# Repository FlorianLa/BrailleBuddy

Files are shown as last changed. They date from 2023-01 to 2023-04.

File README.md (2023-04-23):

#### General Information and Disclaimer
This repository is linked with a scientific publication, which you can find here (https://dl.acm.org/doi/10.1145/3544548.3580844). The HTML version of the article can be accessed here (https://dl.acm.org/doi/fullHtml/10.1145/3544548.3580844). The PDF is contained in this repository.

Our work is published under GNU GPLv3. However, for some files, e.g., 3D figurines or the published paper, other licenses may apply. 
This repository (or rather the releases of this repository) is mirrored on Zenodo.org (https://doi.org/10.5281/zenodo.7606193).

If you use or extend our work, please cite us as (see bibtex_LangEtAl_BrailleBuddy.bib):

*Florian Lang, Verena Pues, Albrecht Schmidt, and Tonja-Katrin Machulla. 2023. BrailleBuddy: A Tangible User Interface to Support Children with Visual Impairment in Learning Braille. In Proceedings of the 2023 CHI Conference on Human Factors in Computing Systems (CHI '23). Association for Computing Machinery, New York, NY, USA, Article 218, 1–14. https://doi.org/10.1145/3544548.3580844*

## BrailleBuddy

BrailleBuddy is a tangible user interface supporting children with visual impairments in learning Braille. It was created using a human-centered inclusive design process with interviews, six design iterations with prototypes, and feedback from experts, students, and teachers. Alleviating the need for supervision, the device can be used during breaks in school or at home, providing additional opportunities to experience Braille and individual audio feedback to support the users in learning to read and spell Braille.

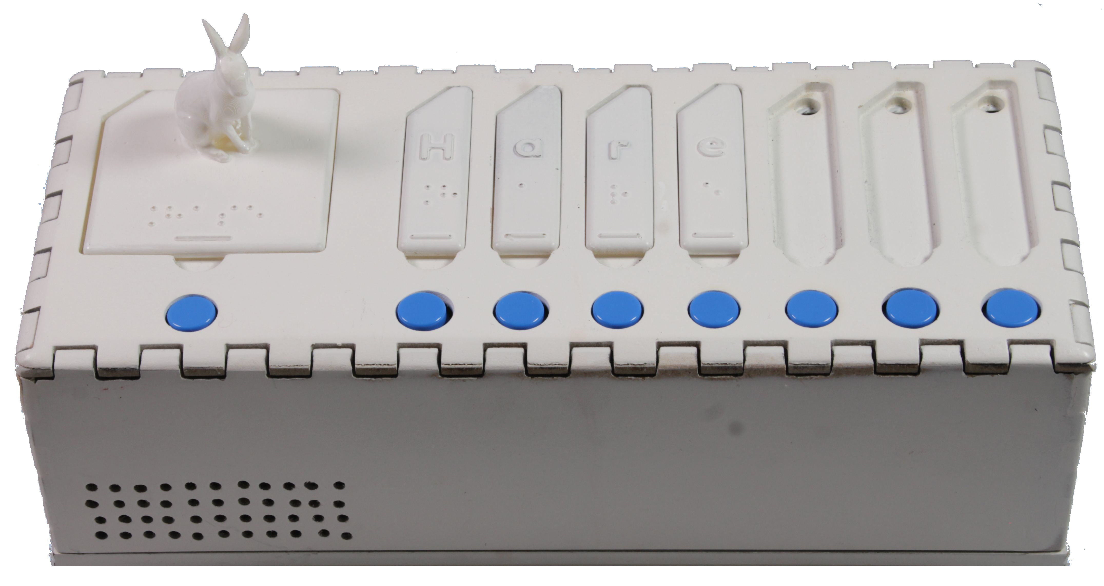
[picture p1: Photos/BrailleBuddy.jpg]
BrailleBuddy


### Case and 3D-printed Cards
We provide a *.svg file for the wooden case of BrailleBuddy in "CaseModel(Lasercutter)". The lid is constructed from two layers of wood. Please be aware, that the files are designed for material with 3mm thickness for each of the layers of the lid and 5mm for the other parts. If you use other materials, you need to adjust the contact areas accordingly.

Further, we provide language specific 3D-models for all cards used. **Right now only the German version is populated, but the models can be used by changing the Braille text beneath the figurine.**
The sources for the 3D figurines are listed next to each card. The 2D relief images were created by [Verena Pues](https://verenapues.com/).

### Supported Languages

**German** - with Braille system "Vollbraille". This version was used in the study.

**English** - with Braille system English Grade 2 Braille **(under construction)** 
For the English version, some points need to be completed, such as audio files and letter cards for abbreviations and English game and word cards.

To adjust the source code for the English version please comment out sections marked with GERMAN VERSION and comment in sections with ENGLISH VERSION

### Hardware

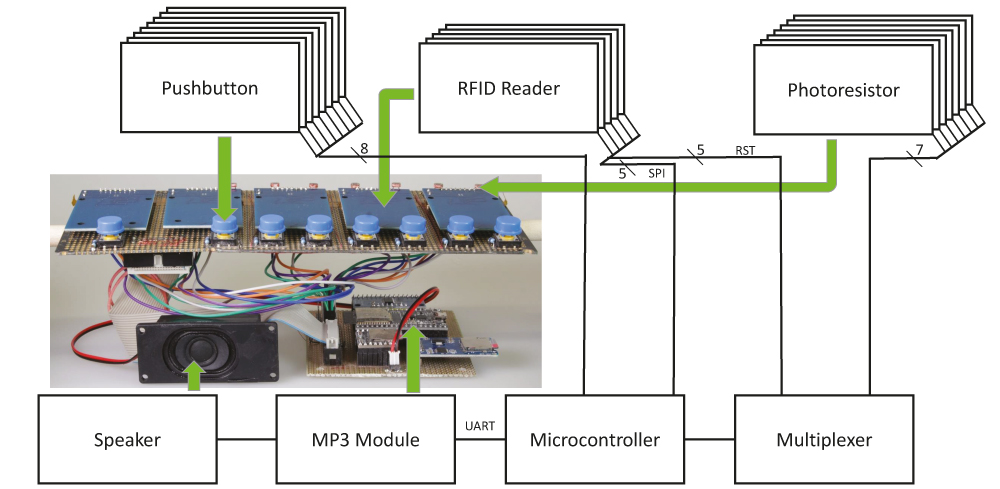
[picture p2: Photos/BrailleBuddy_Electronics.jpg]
Hardware


* **Microcontroller:** The brain of BrailleBuddy is an ESP32 microcontroller board that is easy to program, supports a variety of protocols, and has 27 usable General Purpose Input/Output (GPIO) pins. The board also has Wifi and Bluetooth functionality, which offers numerous possibilities for further development of BraillyBuddy. For other microcontrollers please check if there are enough GPIO pins and adjust the pin layout.
* **NFC Tags:** To store digital information on our game cards, we used NFC Stickers (12 x 19 mm - NTAG213 - 180 Byte - transparent).
* **RFID Readers:** To detect game cards and read and write the digital information, we used 5 x Mifare RFID-RC522 Modules, which communicate with the microcontroller via the SPI interface.
* **Photoresistors:** While the readers are responsible for receiving the information from the NFC tags, we used 7 x light dependent photoresistors to determine the corresponding position for each tag on the box as most of the readers cover two slots. 
* **Multiplexer:** We used a 16 channel digital/analog multiplexer to handle the various needed connections, i.e., to read out the analog signals from the photoresistors and distribute the RFID reader's reset line (RST).
* **MP3 Module and Loudspeaker:** For the auditory feedback, we used a DFPlayer-Mini – a compact serial MP3 module with a built-in amplifier and an SD card slot to store MP3 files – and a small 3 Watt 8 Ohm
loudspeaker.
* **Buttons:** To allow users to repeat the slot-related audio feedback, we used 8 x push buttons (12 x 12 x 7.3 mm).
* **Resistors:** To find out which and how many resistors you need, please consult the respective data sheets of your modules.

### Improvements
We describe various possible improvements for BrailleBuddy in our paper. The most relevant possibilities are:
* Add a headphone connector and an interface to control the volume.
* Instead of reading the word, BrailleBuddy could also make corresponding sounds, e.g., a car or animal sounds.
* Consider differently shaped cards to support users that find correctly rotating and placing the cards challenging.
* Use separate storage areas for the letter cards or reduce the selection of cards presented to support children just starting to learn Braille.
* The audio feedback can be improved by reacting to a button being pressed consecutively multiple times, long times in between cards placed, and multiple incorrectly placed cards. BrailleBuddy could give more diverse responses, e.g., "You placed the correct letter but in the wrong spot." or give hints towards the games solution.

### Pin Layout

| **ESP32 Pin** | **Note** | **Multiplexer** | **MP3 Module** | **RFID Reader** | **Button** |
|---|---|---|---|---|---|
| GPIO 0 | | S1 | | | |
| GPIO 1 | TX | | TX | | |
| GPIO 2 | | S0 | | | |
| GPIO 3 | RX | | RX | | |
| GPIO 4 | | S2 | | | |
| GPIO 5 | | | | No. 3, SDA | |
| GPIO 6 | SPI bus for flash memory, do not use! | | | | |
| GPIO 7 | SPI bus for flash memory, do not use! | | | | |
| GPIO 8 | SPI bus for flash memory, do not use! | | | | |
| GPIO 9 | SPI bus for flash memory, do not use! | | | | |
| GPIO 10 | SPI bus for flash memory, do not use! | | | | |
| GPIO 11 | SPI bus for flash memory, do not use! | | | | |
| GPIO 12 | | | | | |
| GPIO 13 | | | | No. 4, SDA | |
| GPIO 14 | | | | | No. 8 |
| GPIO 15 | used as Reader RST Pin | SIG | | | |
| GPIO 16 | | S3 | | | |
| GPIO 17 | | | | No. 5, SDA | |
| GPIO 18 | CLK | | | All, SCK | |
| GPIO 19 | MISO | | | All, MISO | |
| GPIO 21 | | | | No. 2, SDA | |
| GPIO 22 | | | | No. 1, SDA | |
| GPIO 23 | MOSI | | | All, MOSI | |
| GPIO 25 | | | | | No. 5 |
| GPIO 26 | | | | | No. 6 |
| GPIO 27 | | | | | No. 7 |
| GPIO 32 | | | | | No. 3 |
| GPIO 33 | | | | | No. 4 |
| GPIO 34 | only input | | | | No. 1 |
| GPIO 35 | only input | | | | No. 2 |
| GPIO 36 | only input | | | | |
| GPIO 39 | only input | | BUSY | | |

### Audio Files

We used the following free text-to-speech converter to create most audio files: https://ttsmp3.com/.

The sources of the sound effects used are:
* wrong answer: https://pixabay.com/de/sound-effects/wrong-answer-126515/
* correct answer: https://pixabay.com/de/sound-effects/success-1-6297/
* evaluation drums: https://pixabay.com/de/sound-effects/tadaa-47995/
* dice rolling for word scramble game intro: https://pixabay.com/de/sound-effects/dice-cup-60668/

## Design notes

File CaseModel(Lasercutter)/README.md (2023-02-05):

## BrailleBuddy Case

Dimensions: 250 x 105 x 80 mm

Braille Buddy's Box case was made from MDF wood boards (3mm and 5mm) using a Lasercutter.
All Elements were cut from 5mm thick boards, except the box lid. 
The lid consists of two layers, each 3mm thick. The bottom layer serves as a storage surface for the playing cards while the top layer contains the indentations that show where cards can be placed.

For a more pleasant touch experience, the wooden surface has been sanded, the corners rounded and the entire box lacquered.

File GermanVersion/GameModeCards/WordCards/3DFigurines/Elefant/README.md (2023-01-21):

Based on:
"G象（Elephant）3Dデータ" by YahooJAPAN
https://www.thingiverse.com/thing:182136
licensed under the Creative Commons - Attribution license (https://creativecommons.org/licenses/by/4.0/)

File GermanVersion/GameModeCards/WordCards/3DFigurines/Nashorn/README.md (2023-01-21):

Based on:
"サイ（Rhino）3Dデータ" by YahooJAPAN
https://www.thingiverse.com/thing:182261
licensed under the Creative Commons - Attribution license (https://creativecommons.org/licenses/by/4.0/)

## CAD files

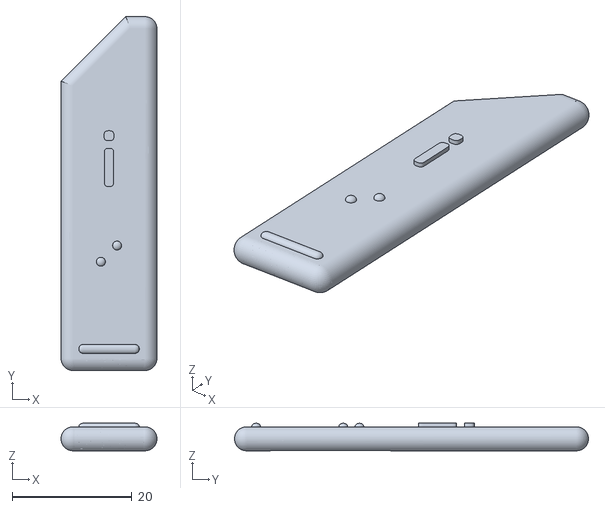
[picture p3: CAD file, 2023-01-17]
EnglishVersion/LetterCards/Lowercase/i.stl
16.0 x 59.0 x 4.60

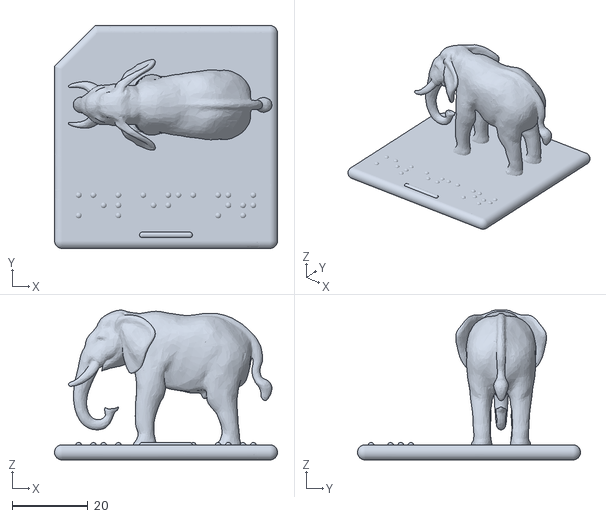
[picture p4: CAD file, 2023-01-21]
GermanVersion/GameModeCards/WordCards/3DFigurines/Elefant/Elefant_3D.stl
59.0 x 59.0 x 39.7

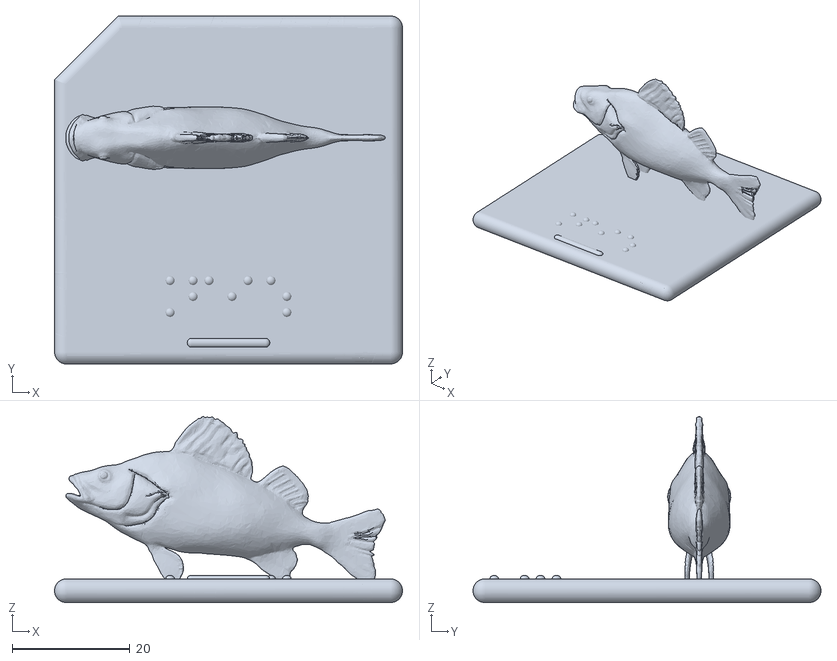
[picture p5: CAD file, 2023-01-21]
GermanVersion/GameModeCards/WordCards/3DFigurines/Fisch/Fisch_3D.stl
59.0 x 59.0 x 31.5

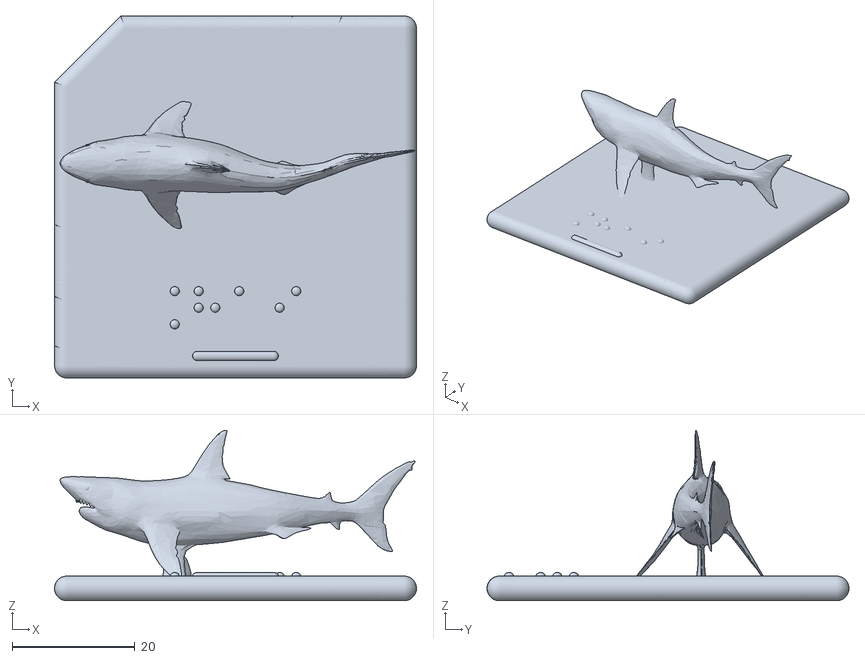
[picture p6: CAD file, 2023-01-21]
GermanVersion/GameModeCards/WordCards/3DFigurines/Hai/Hai_3D.stl
59.0 x 59.0 x 27.8

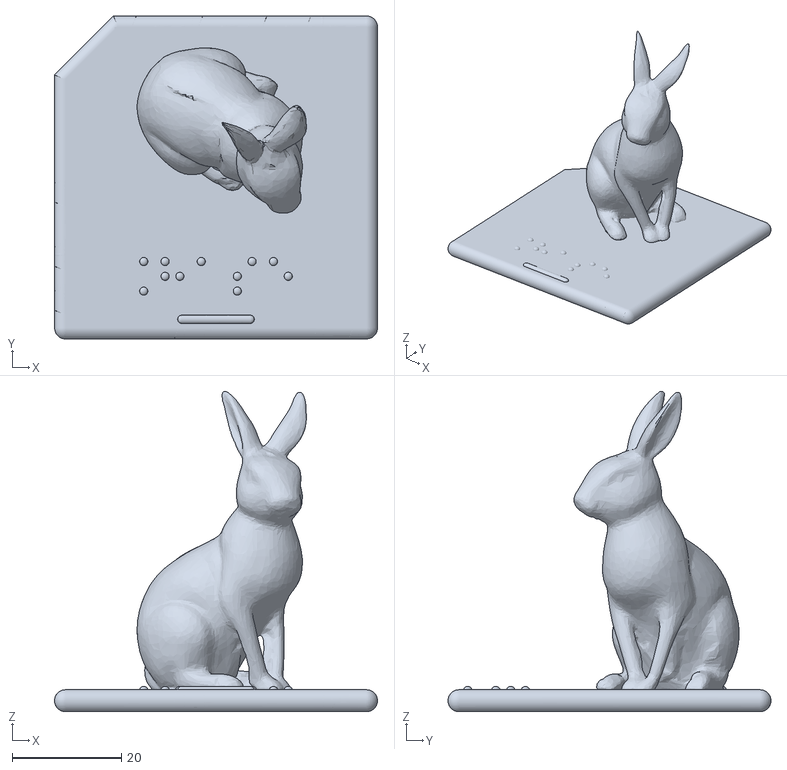
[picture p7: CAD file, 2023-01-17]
GermanVersion/GameModeCards/WordCards/3DFigurines/Hase/Hase_3D.stl
59.0 x 59.0 x 58.5

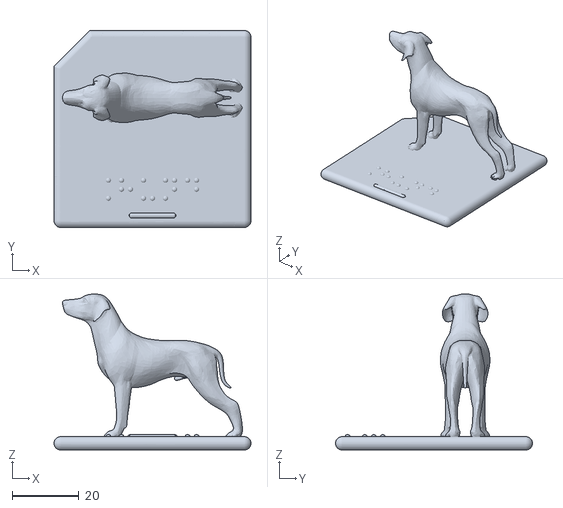
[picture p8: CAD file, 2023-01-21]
GermanVersion/GameModeCards/WordCards/3DFigurines/Hund/Hund_3D.stl
59.0 x 59.0 x 46.7

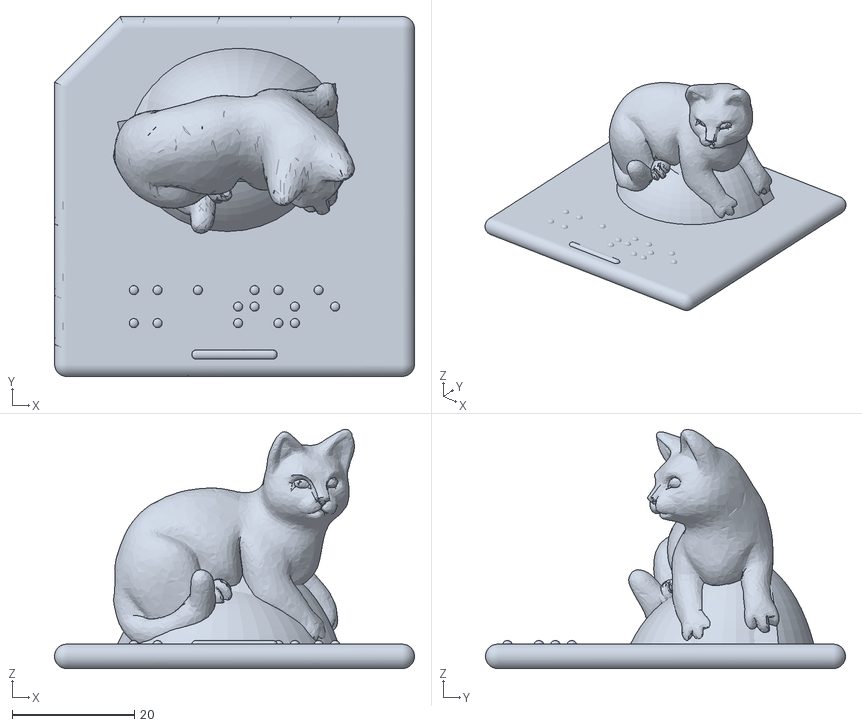
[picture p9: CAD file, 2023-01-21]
GermanVersion/GameModeCards/WordCards/3DFigurines/Katze/Katze_3D.stl
59.0 x 59.0 x 39.2

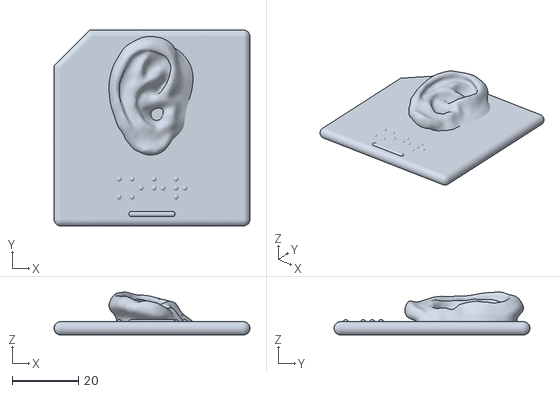
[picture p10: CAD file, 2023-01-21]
GermanVersion/GameModeCards/WordCards/3DFigurines/Ohr/Ohr_3D.stl
59.0 x 59.0 x 12.9

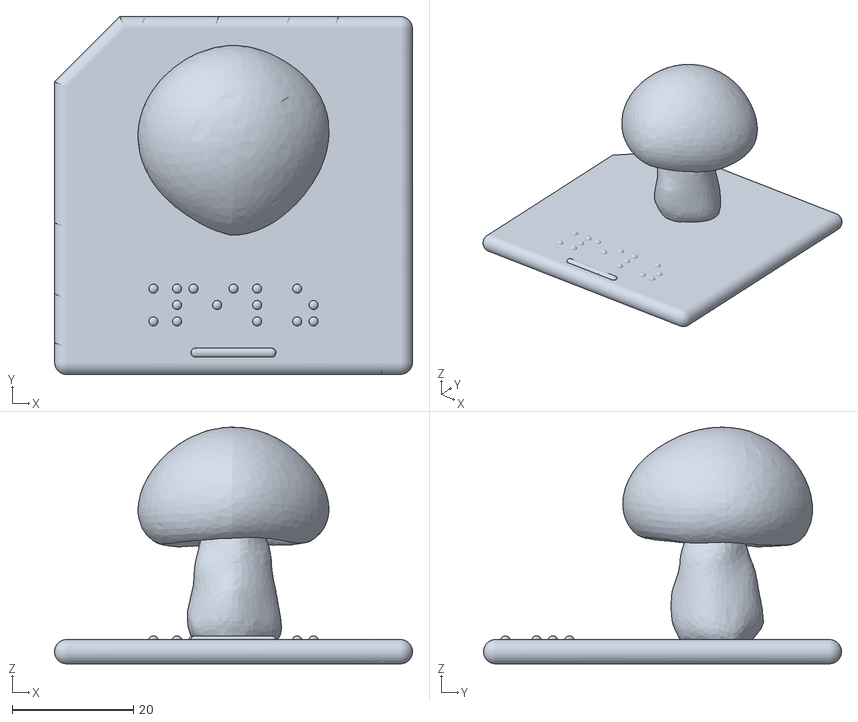
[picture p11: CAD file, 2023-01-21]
GermanVersion/GameModeCards/WordCards/3DFigurines/Pilz/Pilz_3D.stl
59.0 x 59.0 x 39.0

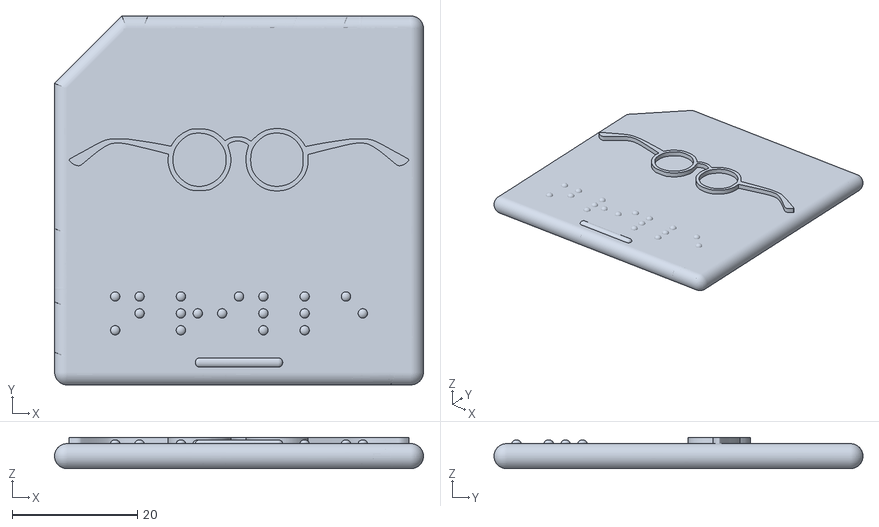
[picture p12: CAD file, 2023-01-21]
GermanVersion/GameModeCards/WordCards/Relief/Wortkarte links Brille.stl
59.0 x 59.0 x 5.00

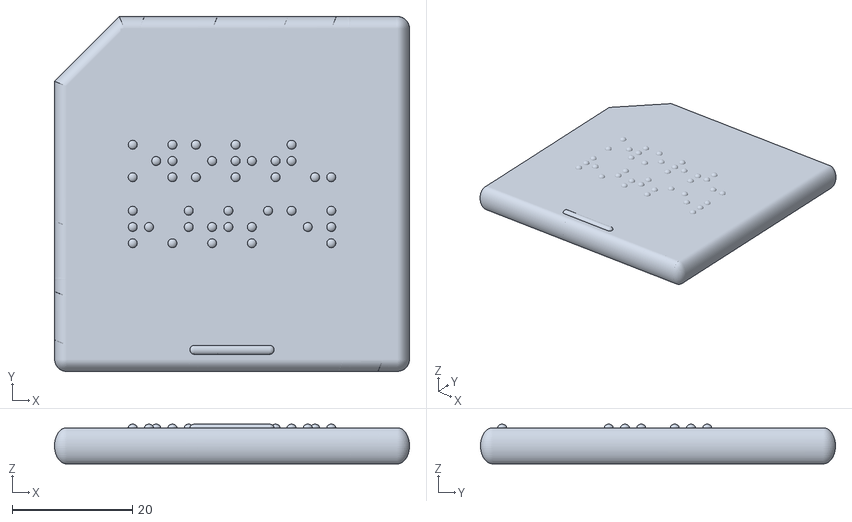
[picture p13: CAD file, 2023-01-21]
GermanVersion/GameModeCards/WortRätsel.stl
59.0 x 59.0 x 6.60

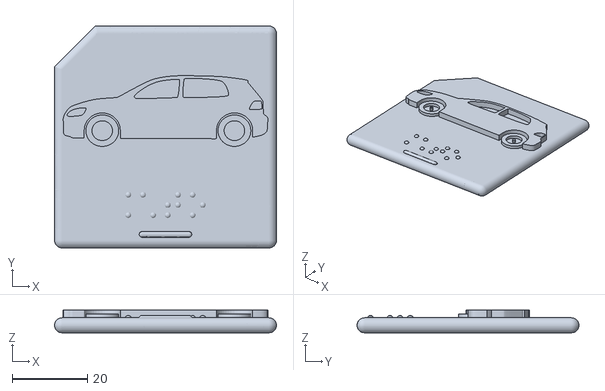
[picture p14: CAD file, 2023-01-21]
GermanVersion/GameModeCards/WordCards/Relief/Wortkarte links Auto.stl
59.0 x 59.0 x 6.00

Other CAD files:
GermanVersion/LetterCards/Lowercase/ei.stl
EnglishVersion/LetterCards/Lowercase/r.stl
GermanVersion/GameModeCards/WordCards/Relief/Wortkarte links Banane.stl
GermanVersion/LetterCards/Lowercase/aUml.stl
EnglishVersion/LetterCards/Lowercase/u.stl
GermanVersion/LetterCards/Lowercase/szlig.stl
EnglishVersion/LetterCards/Lowercase/a.stl
EnglishVersion/LetterCards/Lowercase/b.stl
EnglishVersion/LetterCards/Lowercase/c.stl
EnglishVersion/LetterCards/Lowercase/d.stl
EnglishVersion/LetterCards/Lowercase/e.stl
EnglishVersion/LetterCards/Lowercase/f.stl
EnglishVersion/LetterCards/Lowercase/g.stl
EnglishVersion/LetterCards/Lowercase/h.stl
EnglishVersion/LetterCards/Lowercase/j.stl
EnglishVersion/LetterCards/Lowercase/k.stl
EnglishVersion/LetterCards/Lowercase/l.stl
EnglishVersion/LetterCards/Lowercase/m.stl
EnglishVersion/LetterCards/Lowercase/n.stl
EnglishVersion/LetterCards/Lowercase/o.stl
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

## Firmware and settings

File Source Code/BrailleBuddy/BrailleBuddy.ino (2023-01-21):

#include <SPI.h>
#include <MFRC522.h>
#include "DFRobotDFPlayerMini.h"

//defines the number of letter/char slots
#define NR_OF_CHAR_POS 7
//defines the number of RFID readers
#define NR_OF_READERS 5
//defines the audio queue size
#define AUDIO_QUEUE_SIZE 10
//defines the max. audio feeback size/
// which is the max. number of audio files combined together for the feedback
#define AUDIO_FEEDBACK_SIZE 9

//====================== Enums for GAME MODES =====================================
enum GameModes {
  NO_GAME,
  COPY_WORD,
  WORD_SCRAMBLE,
  WORD_RIDDLE
};

enum GameSubModes {
  NO_SUB,
  COPY_WORD_FINISHED,
  WORD_SCRAMBLE_PLACE_LETTERS,
  WORD_SCRAMBLE_SORT_LETTERS,
  WORD_SCRAMBLE_FINISHED,
  WORD_RIDDLE_FINISHED
};

//====================== Custom Type Definitions ===================================

// The Audio files need a folder and a track number to define where to find them on the SD card
typedef struct {
  int folder;
  int track;
} Audio;

// Each braille char has a matching audio file, a string representation (i.e. "a")
// and a occurance to distinguish same braille chars (a char can appear multiple times in a word)
typedef struct {
  Audio audio;
  int occurance;
  String value;
} BrailleChar;

//Each word has a matching audio file and a number of brailleChars it consists of
typedef struct {
  Audio audio;
  BrailleChar brailleChars[7];
} BrailleWord;

//Each NFC tag has a matching audio file, a possible occurance (if its a letter tag), 
// a possible game mode (if its a game mode tag), and string information (i.e. "Sch", "a", "f" for a word tag)
typedef struct {
  Audio audio;
  int occurance;
  GameModes gameMode;
  String values[7];
} Tag;

//=================================== Audio Feedback =====================================

// index of first lowercase letter in the letter audio folder **GERMAN VERSION**
#define INDEX_OF_FIRST_LOWERCASE_LETTER 37

// index of first lowercase letter in the letter audio folder **ENGLISH VERSION**
// #define INDEX_OF_FIRST_LOWERCASE_LETTER 26

HardwareSerial mySoftwareSerial(1);
DFRobotDFPlayerMini myDFPlayer;

// audioQueue stores the order in which the files should be played
Audio audioQueue[AUDIO_QUEUE_SIZE] = {{0}, {0}, {0}, {0}, {0}, {0}, {0}, {0}, {0}, {0}};
// stores the audio feedback sequence for a letter
Audio charAudioFeedback[NR_OF_CHAR_POS][AUDIO_FEEDBACK_SIZE];
// is used to overwrite the letter's audio feedback when a letter tag is removed
Audio audioFeedbackLeeresFeld[AUDIO_FEEDBACK_SIZE] = {{1, 1}, {0, 0}, {0, 0}, {0, 0}, {0, 0}, {0, 0}, {0, 0}, {0, 0}, {0, 0}};

// is used to stop the program loop while audio feedback for the switch of a game state is being played
// as this must not be skipped to make sure the user knows about the game mode switch
boolean eval = false;

// the busy pin is used to check whether the mp3 player is actually playing
byte mp3PlayerBusyPin = 39;
// tells whether the mp3Player is currently busy with playing audio
boolean mp3PlayerBusy = false;
// represents the current busy value (either HIGH or LOW)
byte currentBusyValue;
// is used to check whether the busy value has changed
byte prevBusyValue;


Audio hello = {1, 0};
Audio evaluationCorrectFanfare = {1, 4};
Audio copyWordsCapCharMissing = {1, 12};
Audio gameCardRemoved = {1, 13};

Audio copyWordsIntro = {3, 0};

Audio welcomeToWordScramble = {4, 0};
Audio wordScrambleIntro = {4, 1};
Audio wordScrambleLettersWerePlacedInCorrectOrder = {4, 2};
Audio wordScrambleHowToStartNewGameRound = {4, 3};
Audio wordScrambleSolution = {4, 4};

Audio wordRiddleWelcome = {5, 0};
Audio wordRiddleIntro1 = {5, 1};
Audio wordRiddleIntro2 = {5, 2};
Audio wordRiddleBrailleCharacters = {5, 9};
Audio wordRiddleIncludingLeadingCapsChar = {5, 10};
Audio wordRiddleInstruction = {5, 11};
Audio wordRiddleNotIncluded = {5, 12};
Audio wordRiddleButAtAnotherPosition = {5, 13};
Audio wordRiddleAndRightPosition = {5, 14};
Audio wordRiddleWordFound = {5, 15};
Audio wordRiddleIncludedOnce = {5, 16};
Audio wordRiddleIncludedTwice = {5, 17};
Audio wordRiddleIncludedThreeTimes = {5, 18};
Audio wordRiddleIncludedFourTimes = {5, 19};
Audio wordRiddleOneUppercase = {5, 20};
Audio wordRiddleButLowercaseIs = {5, 21};
Audio wordRiddleButUppercaseIs = {5, 22};
Audio wordRiddleIsIncluded = {5, 23};

//=================================== RFID Readers =====================================

MFRC522 mfrc522[NR_OF_READERS]; // initialize the RFID reader instances 

// tells which reader is currently active (as only one reader is active at a time to prevent interference)
int currentlyActiveReader = -1;

// slave select pins of readers, is used to define with which reader we want to communicate
byte ssReaderPins[NR_OF_READERS] = {22, 21, 5, 13, 17};
// reset pin is shared by all readers and is used to deactivate a reader (see also: multiplexer)
byte rstReaderPin = 15;
// defines which reader is responsible for which letter position on the box
// i.e. reader with index 4 is responsible to read values for position 6 and 7
byte readerForPos[NR_OF_CHAR_POS] = {1, 2, 2, 3, 3, 4, 4};

// the denominator used to divide a word into braille chars on the NFC tags
char denom = '-';

//=================================== Photoresistors =====================================

// holds information about the current light situation at each letter slot
int photovalues[NR_OF_CHAR_POS] = {0, 0, 0, 0, 0, 0, 0};
// stores the initial light situation read at each letter slot at the initial setup
// to decide whether the light situation has changed
int initialPhotovalues[NR_OF_CHAR_POS] = {0, 0, 0, 0, 0, 0, 0};

//=================================== Multiplexer ========================================

// pins used to switch between multiplexed channels
byte multiplexerPins[4] = {2, 0, 4, 16};
// pin used to read or write to the selected channel
byte multiplexerSignalPin = 15;

// the photoresistors are being multiplexed
int mpPhotoSelection[NR_OF_CHAR_POS][4] = {
  {0, 1, 1, 0}, {1, 0, 1, 0}, {0, 0, 1, 0}, {1, 1, 0, 0}, {0, 1, 0, 0}, {1, 0, 0, 0}, {0, 0, 0, 0}
};
// the multiplexers reset inputs are being multiplexed
int rstSelection[NR_OF_READERS][4] = {
  {1, 1, 0, 1}, {0, 1, 0, 1}, {1, 0, 0, 1}, {0, 0, 0, 1}, {1, 1, 1, 0}
};


//=================================== Buttons ========================================

byte btnPins[8] = {34, 35, 32, 33, 25, 26, 27, 14};
byte btnStates[8] = {LOW, LOW, LOW, LOW, LOW, LOW, LOW, LOW};
byte btnStatesPrev[8] = {LOW, LOW, LOW, LOW, LOW, LOW, LOW, LOW};

//=============================== Game Information ===================================

// stores current game mode 
GameModes currentGameMode = NO_GAME;
// is used to check for a game mode change
GameModes prevGameMode = NO_GAME;


// stores current sub game mode 
GameSubModes currentGameSubMode = NO_SUB;
// is used to check for a sub game mode change
GameSubModes prevGameSubMode = NO_SUB;

// represents the current letters on the BrailleBox
BrailleChar currentCharState[NR_OF_CHAR_POS] = {{0}, {0}, {0}, {0}, {0}, {0}, {0}};
// stores the goal char state for the current (sub) game mode
BrailleChar wantedCharState[NR_OF_CHAR_POS] = {{0}, {0}, {0}, {0}, {0}, {0}, {0}};
// holds information such as audio file etc. for the current word solution
BrailleWord wordTemplate = {0};

// if no game mode card is read from the first reader the empty word counter gets counted up to empty threshold
// to make sure the slot is really empty and it wasn't just a reader fail
int emptyWordCounter = 0;
int emptyThreshold = 3;


//================ Word Collection for Purzelwörter (Word Scramble) and Worträtsel (Word Riddle) ============================
/* In the future this information should be expanded to a full primary school dictionary and be stored on a extra SD Card */

// collection of all needed braille char information **GERMAN VERSION START**
BrailleChar aUppercase = {2, 0, 1, "A"};
BrailleChar bUppercase = {2, 1, 1, "B"};
BrailleChar cUppercase = {2, 2, 1, "C"};
BrailleChar dUppercase = {2, 3, 1, "D"};
BrailleChar eUppercase = {2, 4, 1, "E"};
BrailleChar fUppercase = {2, 5, 1, "F"};
BrailleChar gUppercase = {2, 6, 1, "G"};
BrailleChar hUppercase = {2, 7, 1, "H"};
BrailleChar iUppercase = {2, 8, 1, "I"};
BrailleChar jUppercase = {2, 9, 1, "J"};
BrailleChar kUppercase = {2, 10, 1, "K"};
BrailleChar lUppercase = {2, 11, 1, "L"};
BrailleChar mUppercase = {2, 12, 1, "M"};
BrailleChar nUppercase = {2, 13, 1, "N"};
BrailleChar oUppercase = {2, 14, 1, "O"};
BrailleChar pUppercase = {2, 15, 1, "P"};
BrailleChar qUppercase = {2, 16, 1, "Q"};
BrailleChar rUppercase = {2, 17, 1, "R"};
BrailleChar sUppercase = {2, 18, 1, "S"};
BrailleChar tUppercase = {2, 19, 1, "T"};
BrailleChar uUppercase = {2, 20, 1, "U"};
BrailleChar vUppercase = {2, 21, 1, "V"};
BrailleChar wUppercase = {2, 22, 1, "W"};
BrailleChar xUppercase = {2, 23, 1, "X"};
BrailleChar yUppercase = {2, 24, 1, "Y"};
BrailleChar zUppercase = {2, 25, 1, "Z"};
BrailleChar aeUppercase = {2, 26, 1, "Ae"};
BrailleChar oeUppercase = {2, 27, 1, "Oe"};
BrailleChar ueUppercase = {2, 28, 1, "Ue"};
BrailleChar auUppercase = {2, 29, 1, "Au"};
BrailleChar chUppercase = {2, 30, 1, "Ch"};
BrailleChar eiUppercase = {2, 31, 1, "Ei"};
BrailleChar euUppercase = {2, 32, 1, "Eu"};
BrailleChar ieUppercase = {2, 33, 1, "Ie"};
BrailleChar schUppercase = {2, 34, 1, "Sch"};
BrailleChar stUppercase = {2, 35, 1, "St"};
BrailleChar aeuUppercase = {2, 36, 1, "Aeu"};

BrailleChar aLowercase = {2, 37, 1, "a"};
BrailleChar bLowercase = {2, 38, 1, "b"};
BrailleChar cLowercase = {2, 39, 1, "c"};
BrailleChar dLowercase = {2, 40, 1, "d"};
BrailleChar eLowercase = {2, 41, 1, "e"};
BrailleChar fLowercase = {2, 42, 1, "f"};
BrailleChar gLowercase = {2, 43, 1, "g"};
BrailleChar hLowercase = {2, 44, 1, "h"};
BrailleChar iLowercase = {2, 45, 1, "i"};
BrailleChar jLowercase = {2, 46, 1, "j"};
BrailleChar kLowercase = {2, 47, 1, "k"};
BrailleChar lLowercase = {2, 48, 1, "l"};
BrailleChar mLowercase = {2, 49, 1, "m"};
BrailleChar nLowercase = {2, 50, 1, "n"};
BrailleChar oLowercase = {2, 51, 1, "o"};
BrailleChar pLowercase = {2, 52, 1, "p"};
BrailleChar qLowercase = {2, 53, 1, "q"};
BrailleChar rLowercase = {2, 54, 1, "r"};
BrailleChar sLowercase = {2, 55, 1, "s"};
BrailleChar tLowercase = {2, 56, 1, "t"};
BrailleChar uLowercase = {2, 57, 1, "u"};
BrailleChar vLowercase = {2, 58, 1, "v"};
BrailleChar wLowercase = {2, 59, 1, "w"};
BrailleChar xLowercase = {2, 60, 1, "x"};
BrailleChar yLowercase = {2, 61, 1, "y"};
BrailleChar zLowercase = {2, 62, 1, "z"};
BrailleChar aeLowercase = {2, 63, 1, "ae"};
BrailleChar oeLowercase = {2, 64, 1, "oe"};
BrailleChar ueLowercase = {2, 65, 1, "ue"};
BrailleChar auLowercase = {2, 66, 1, "au"};
BrailleChar chLowercase = {2, 67, 1, "ch"};
BrailleChar eiLowercase = {2, 68, 1, "ei"};
BrailleChar euLowercase = {2, 69, 1, "eu"};
BrailleChar ieLowercase = {2, 70, 1, "ie"};
BrailleChar schLowercase = {2, 71, 1, "sch"};
BrailleChar stLowercase = {2, 72, 1, "st"};
BrailleChar aeuLowercase = {2, 73, 1, "aeu"};
BrailleChar ssLowercase = {2, 74, 1, "ss"};
// collection of all needed braille char information **GERMAN VERSION END**

// collection of all needed braille char information **ENGLISH VERSION START**
// TODO: include english grade 2 braille abbreviation characters to audiofiles
/*BrailleChar aLowercase = {2, 26, 1, "a"};
BrailleChar bLowercase = {2, 27, 1, "b"};
BrailleChar cLowercase = {2, 28, 1, "c"};
BrailleChar dLowercase = {2, 29, 1, "d"};
BrailleChar eLowercase = {2, 30, 1, "e"};
BrailleChar fLowercase = {2, 31, 1, "f"};
BrailleChar gLowercase = {2, 32, 1, "g"};
BrailleChar hLowercase = {2, 33, 1, "h"};
BrailleChar iLowercase = {2, 34, 1, "i"};
BrailleChar jLowercase = {2, 35, 1, "j"};
BrailleChar kLowercase = {2, 36, 1, "k"};
BrailleChar lLowercase = {2, 37, 1, "l"};
BrailleChar mLowercase = {2, 38, 1, "m"};
BrailleChar nLowercase = {2, 39, 1, "n"};
BrailleChar oLowercase = {2, 40, 1, "o"};
BrailleChar pLowercase = {2, 41, 1, "p"};
BrailleChar qLowercase = {2, 42, 1, "q"};
BrailleChar rLowercase = {2, 43, 1, "r"};
BrailleChar sLowercase = {2, 44, 1, "s"};
BrailleChar tLowercase = {2, 45, 1, "t"};
BrailleChar uLowercase = {2, 46, 1, "u"};
BrailleChar vLowercase = {2, 47, 1, "v"};
BrailleChar wLowercase = {2, 48, 1, "w"};
BrailleChar xLowercase = {2, 49, 1, "x"};
BrailleChar yLowercase = {2, 50, 1, "y"};
BrailleChar zLowercase = {2, 51, 1, "z"};*/
// collection of all needed braille char information **ENGLISH VERSION END**
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
void loop() {
  if (!eval) { // if no game mode switch with important audio information is happening
    readPhotoValues(); // then update the photovalues
    checkGameMode(); // check current game mode
    checkBrailleCharsState(); // check current letter state
    setGameSubMode(); // set sub game mode depending on current game mode
    handleGameSubModeChange(); // check for a possible sub mode change and handle it
    checkButtons(); // look for button input
    //debug();
  }
  playAudio(); 
}

// ======================== methods for general game handling ===========================================

void checkGameMode() {
  
  // start reader at first position (game mode position)
  int reader = 0;
  initReader(reader);

  // check if a game mode card is present
  if (newTagPresent(reader)) {
    // reset empty word counter
    emptyWordCounter = 0;
    Tag currentTag = readTag(reader);
    // update game mode 
    prevGameMode = currentGameMode;
    currentGameMode = currentTag.gameMode;
    // if game mode has changed or a new word for the Worte Nachlegen / Word Copy game is present, start new game
    if (currentGameMode != prevGameMode || (currentGameMode == COPY_WORD && isNewWord(currentTag))) {
      initGame(currentTag);
    }
  } else {
    // if no game mode card is present, empty the word template
    emptyWordTemplate();
  }
  
  // stop communication
  mfrc522[reader].PICC_HaltA();
  mfrc522[reader].PCD_StopCrypto1();
  
}

void checkBrailleCharsState() {

  // for all letter positions...
  for (int i = 0; i < NR_OF_CHAR_POS ; i++) {

    // pick the responsible RFID reader
    int reader = readerForPos[i];
    initReader(reader);

    // as there are possibly two tags in the range of the reader, we have to loop over both of them to decide which one is valid for the current position
    for (int j = 0; j < 2; j++) {
      if (isCharPosEmpty(i)) { // if no letter is already stored for that position
        if (isPosCovered(i) && newTagPresent(reader)) { // check if a new tag is present for that reader (as mentioned above we have to check twice)
          BrailleChar bChar = readBrailleChar(reader); // convert tag information to braille char representation
          boolean isNew = isNewBrailleChar(bChar); // check if the letter was newly added to the box or was already recognized
          
          if (isNew) { // is it is a new letter...
            currentCharState[i] = bChar; // update char state
            
            // log event information for study
            Serial.print("New letter was placed: "); Serial.print(bChar.value); Serial.print(" position: "); Serial.println(i);
            debug();
            printCurrentWordTemplate();
            printWantedCharState();
            printCurrentCharState();
            
            // set audio feedback:...
            // ...letter sound, ...
            charAudioFeedback[i][0] = currentCharState[i].audio;
            // ...additional hints ...
            for (int a = 1; a < AUDIO_FEEDBACK_SIZE; a++) {
              charAudioFeedback[i][a] = calcCharAdditionalAudioFeedback(i, a);
            }
            //... feedback sound effect (correct or incorrect)
            charAudioFeedback[i][AUDIO_FEEDBACK_SIZE - 1] = calcCharAudioFeedback(i);
            
            // overwrite audio queue
            forceUpdateAudioQueue(charAudioFeedback[i][0]);
            for (int a = 1; a < AUDIO_FEEDBACK_SIZE; a++) {
              addToAudioQueue(charAudioFeedback[i][a]);
            }
            // play audio
            playAudio();
          }
        }

        // stop communication with that tag
        mfrc522[reader].PICC_HaltA();
        mfrc522[reader].PCD_StopCrypto1();
      }
    }

    // if there is no card recognized by the photoresistors
    if (!isPosCovered(i)) {
      
      BrailleChar bChar = currentCharState[i];
      // empty the char state position
      currentCharState[i] = {0};
      // update audio feedback to "leeres feld" / "empty slot"
      charAudioFeedback[i][0] = audioFeedbackLeeresFeld[0];
      // empty other audio feedback
      for (int a = 1; a < AUDIO_FEEDBACK_SIZE; a++) {
        charAudioFeedback[i][a] = {0};
      }
      if (bChar.occurance != 0) { // if pos wasn't already empty in a prior check
        // log event information for study
        Serial.print("Letter was removed: "); Serial.print(bChar.value); Serial.print(" position: "); Serial.println(i);
        printCurrentWordTemplate();
        printWantedCharState();
        printCurrentCharState();
      }
    }
  }
}

//returns the soundeffect for either a positive or negative feedback
Audio calcCharAudioFeedback(int pos) {
  if (currentGameMode == NO_GAME) {
    return {0, 0}; // no sfx
  } else {
    if (currentCharState[pos].audio.folder != 0 && currentStateMatchesWantedState(pos)) {
      return {1, 2}; // correct sfx
    } else if (currentCharState[pos].audio.folder != 0 && !currentStateMatchesWantedState(pos)) {
      return {1, 3}; // wrong sfx
    }
  }
  return {0, 0}; // no sfx
}

//returns the spoken text, that adds to the feedback sound effect
Audio calcCharAdditionalAudioFeedback(int pos, int feedbackCounter) {
  if (currentGameMode == NO_GAME) {
    return {0, 0};
  } else if (currentGameMode == COPY_WORD && feedbackCounter == 1) {
    return copyWords_calcCharAdditionalAudioFeedback(pos);
  } else if (currentGameMode == WORD_SCRAMBLE && feedbackCounter == 1) {
    return wordScramble_calcCharAdditionalAudioFeedback(pos);
  } else if (currentGameMode == WORD_RIDDLE) {
    return wordRiddle_calcCharAdditionalAudioFeedback(pos, feedbackCounter);
  }
  return {0, 0};
}

// initializes a game dependend on current game mode
void initGame(Tag tag) {
  if (currentGameMode == NO_GAME) {
    wordTemplate = {0}; // empty template
  } else if (currentGameMode == COPY_WORD) {
    copyWords_initGame(tag);
  } else if (currentGameMode == WORD_SCRAMBLE) {
    wordScramble_initGame();
  } else if (currentGameMode == WORD_RIDDLE) {
    wordRiddle_initGame();
  }
}

bool currentStateMatchesWantedState(int pos) {
  return currentCharState[pos].value == wantedCharState[pos].value;
}

// decides for the sub game mode depending on current game mode 
void setGameSubMode() {
  if (currentGameMode == NO_GAME) {
    prevGameSubMode = currentGameSubMode;
    currentGameSubMode = NO_SUB;
  } else if (currentGameMode == COPY_WORD) {
    if (copyWords_istBeendet()) {
      prevGameSubMode = currentGameSubMode;
      currentGameSubMode = COPY_WORD_FINISHED;
    } else {
      prevGameSubMode = currentGameSubMode;
      currentGameSubMode = NO_SUB;
    }
  } else if (currentGameMode == WORD_SCRAMBLE) {
    if (currentGameSubMode == WORD_SCRAMBLE_PLACE_LETTERS && wordScramble_allLettersPlaced()) {
      prevGameSubMode = currentGameSubMode;
      currentGameSubMode = WORD_SCRAMBLE_SORT_LETTERS;
    } else if (currentGameSubMode == WORD_SCRAMBLE_SORT_LETTERS && wordScramble_lettersSorted()) {
      prevGameSubMode = currentGameSubMode;
      currentGameSubMode = WORD_SCRAMBLE_FINISHED;
    } else if (currentGameSubMode == WORD_SCRAMBLE_SORT_LETTERS && !wordScramble_lettersSorted()) {
      prevGameSubMode = currentGameSubMode;
      currentGameSubMode = WORD_SCRAMBLE_SORT_LETTERS;
    }
  } else if (currentGameMode == WORD_RIDDLE) {
    if (wordRiddle_isFinished()) {
      prevGameSubMode = currentGameSubMode;
      currentGameSubMode = WORD_RIDDLE_FINISHED;
    } else {
      prevGameSubMode = currentGameSubMode;
      currentGameSubMode = NO_SUB;
    }
  }
}

// handle possible submode change
void handleGameSubModeChange() {
  if (currentGameSubMode != prevGameSubMode) {
    if (currentGameMode == COPY_WORD) {
      copyWords_handleSubModeChange();
    } else if (currentGameMode == WORD_SCRAMBLE) {
      wordScramble_handleSubModeChange();
    } else if (currentGameMode == WORD_RIDDLE) {
      wordRiddle_handleSubModeChange();
    }
  }
}


// ======================== BUTTONS ===========================================

// check for input / if the state of a button has changed
void checkButtons() {
  for (int i = 0; i < 8; i++) {
    btnStatesPrev[i] = btnStates[i];
    btnStates[i] = digitalRead(btnPins[i]);
    if (btnStates[i] == HIGH && btnStates[i] != btnStatesPrev[i]) {
      handleButtonPressed(i);
    }
  }
}
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

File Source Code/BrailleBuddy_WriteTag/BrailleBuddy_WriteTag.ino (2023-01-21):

/**
 * This sample shows how to write the needed game informations on a 
 * MIFARE Ultralight tag that are used for the game and letter cards of BrailleBuddy:
 * https://github.com/FlorianLa/BrailleBuddy
 * --------------------------------------------------------------------------------------------------
 * This sketch is based on a MFRC522 library example: 
 * https://github.com/miguelbalboa/rfid/blob/master/examples/ReadAndWrite/ReadAndWrite.ino
 * See https://github.com/miguelbalboa/rfid for further details and other examples.
 * --------------------------------------------------------------------------------------------------
 * 
 * Pin layout used:
 * --------------------------------------------------------------------------------------------------
 *             MFRC522             
 *             Reader/PCD   ESP32
 * Signal      Pin          Pin             Note
 * --------------------------------------------------------------------------------------------------
 * RST         RST          15              reset pin is used to deactivate a reader, can be any GPIO
 * SPI SS      SDA(SS)      22              select pin for readers, can be any GPIO           
 * SPI MOSI    MOSI         23  
 * SPI MISO    MISO         19  
 * SPI SCK     SCK          18 
 *
 * More pin layouts for other boards can be found here: https://github.com/miguelbalboa/rfid#pin-layout
 *
 */

#include <SPI.h>
#include <MFRC522.h>

#define RST_PIN         22          // Configurable, see pin layout above
#define SS_PIN          5           // Configurable, see pin layout above

MFRC522 mfrc522(SS_PIN, RST_PIN);   // Create MFRC522 instance.

#define NR_OF_ROWS      8           // number of rows we want to write on the tag
#define NR_OR_COLUMNS   4           // a row on our Ultralight tag has the length of 4 bytes
 
void setup() {
  // the code here is run once on setup
  Serial.begin(19200);              // Initialize serial communications with the PC
  while (!Serial);                  // Do nothing if no serial port is opened
  SPI.begin();                      // Init SPI bus
  mfrc522.PCD_Init();               // Init MFRC522 reader
  delay(1000);                      // wait to make sure the reader is ready
  Serial.println("Write Braille Char on a MIFARE PICC");
}

void loop() {
  // Reset the loop if no new card present on the sensor/reader. This saves the entire process when idle.
  if(newTagPresent()){

    //The buffer is the information that should be written on the tag.

    /*The first row stores information about the game mode, audio (track, folder), and occurance
      - game mode: a number from 1 - 3
        only set this number on game mode cards! 
        Lets the BrailleBuddy Box know, which game the player wants to play
        1: Copy Words
        2: Word Scramble
        3: Word Riddle
      - audio: 
          track: index of the audio file inside the folder
          folder: index of the folder sored od the sd card
          (should match your folder/file setup for the MP3 Module's Sd Card)
      - occurance: only needed for letter / character cards
        as there are multiple characters that occure on more than one card
        (e.g. for banana we need 3 a's) each of the letters has it's own occurance id.
        This is needed to check whether a new card was placed on the BrailleBuddy box 
    */

    /*The seven following rows store the character information (up to 7 braille characters).
      Braille characters with more than one letter, e.g. "sh" are stored in one row.
    */

    // Adjust the buffer to match the character or word you want to store on the tag
    // Buffer Example for a single braille character 'd'
    byte buffer[NR_OF_ROWS][NR_OR_COLUMNS] = {
      {0, 29, 2, 1}, // game mode, track, folder, occurance
      {0, 0, 0, 'd'},
      {0, 0, 0, 0},
      {0, 0, 0, 0},
      {0, 0, 0, 0},
      {0, 0, 0, 0},
      {0, 0, 0, 0},
      {0, 0, 0, 0}
    };

    // Buffer Example for the word "Ameise" / "ant"
    /*byte buffer[NR_OF_ROWS][NR_OR_COLUMNS] = {
      {1, 16, 6, 0}, // game mode, track, folder, occurance
      {0, 0, 0, 'A'},
      {0, 0, 0, 'm'},
      {0, 0, 'e', 'i'},
      {0, 0, 0, 's'},
      {0, 0, 0, 'e'},
      {0, 0, 0, 0},
      {0, 0, 0, 0}
    };*/
    /*byte buffer[NR_OF_ROWS][NR_OR_COLUMNS] = {
      {1, 0, 6, 0}, // game mode, track, folder, occurance
      {0, 0, 0, 'a'},
      {0, 0, 0, 'n'},
      {0, 0, 0, 't'},
      {0, 0, 0, 0},
      {0, 0, 0, 0},
      {0, 0, 0, 0},
      {0, 0, 0, 0}
    };*/

    byte page = 6;
    MFRC522::StatusCode status;
    byte len = NR_OR_COLUMNS;

    // Write block
    for(int i = 0; i < NR_OF_ROWS; i++) {
      status = mfrc522[0].MIFARE_Ultralight_Write(page, buffer[i], NR_OR_COLUMNS);
      if (status != MFRC522::STATUS_OK) {
        Serial.print(F("MIFARE_Write() failed: "));
        Serial.println(mfrc522[0].GetStatusCodeName(status));
        return;
      }
      else Serial.println(F("MIFARE_Write() success: "));
      page += 1;
    }

  }
}

bool newTagPresent() {
  return mfrc522.PICC_IsNewCardPresent() && mfrc522.PICC_ReadCardSerial();
}

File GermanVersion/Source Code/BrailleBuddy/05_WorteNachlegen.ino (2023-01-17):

void worteNachlegen_initGame(Tag tag) {
  
  wordTemplate.audio = tag.audio;
  forceUpdateAudioQueue(wordTemplate.audio);
  addToAudioQueue({3, 0});
  freeWordTemplateAndWantedCharState();
  for (int i = 0; i < NR_OF_CHAR_POS; i++) {
    wordTemplate.brailleChars[i].value = tag.values[i];
    wantedCharState[i].value = tag.values[i];
  }

  Serial.println("Spiel Worte Nachlegen gestartet ");
  printCurrentWordTemplate();
  printWantedCharState();
  printCurrentCharState();
  
}

boolean worteNachlegen_istBeendet() {
  boolean result = true;
  for (int i = 0; i < NR_OF_CHAR_POS; i++) {
    if (currentCharState[i].value != wantedCharState[i].value) {
      result = false;
      break;
    }
  }
  return result;
}

void worteNachlegen_handleSubModeChange() {
  if (currentGameSubMode == WORTE_NACHLEGEN_BEENDET) {
    worteNachlegen_handleBeendet(false);
  }
}

void worteNachlegen_handleBeendet(boolean forceFirstAudio) {
  if (forceFirstAudio) {
    forceUpdateAudioQueue({1, 4});
  } else {
    eval = true;
    addToAudioQueue({1, 4});
    Serial.println("Spiel Worte Nachlegen erfolgreich beendet ");
    printCurrentWordTemplate();
    printWantedCharState();
    printCurrentCharState();
  }
  addToAudioQueue(wordTemplate.audio);
  int positiveFeedback = random(7, 11);
  addToAudioQueue({1, positiveFeedback});
}

Audio worteNachlegen_calcCharAdditionalAudioFeedback(int pos) {
  boolean isSmall = currentCharState[pos].audio.track > 36;
  if (
    isSmall
    && wantedCharState[pos].value[0] == toupper(currentCharState[pos].value[0])) {
    return {1, 12}; // Das Großschreibzeichen fehlt;
  }
  return {0, 0};
}

boolean isNewWord(Tag newTag) {
  boolean result = false;
  for (int i = 0; i < NR_OF_CHAR_POS; i++) {
    if (wordTemplate.brailleChars[i].value != newTag.values[i]) {
      result = true;
      break;
    }
  }
  return result;
}

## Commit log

2023-01-17 Intial Commit, folder structure, Sounds and Lettercards by Verena
    [A.stl, AUml.stl, AUmlu.stl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]
2023-01-17 Added Braille Buddy Arduino Source Code
2023-01-21 Added Braille Buddy Arduino Code to write char and game mode info on NFC stickers
2023-01-21 Case svgs for Lasercutter
2023-01-21 renamed audio files from box to buddy 2
    [Hase_3D.stl]
2023-01-21 added relief word cards
    [Hase_3D.stl, WortRätsel.stl, Wortkarte links Ananas.stl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]
2023-01-21 added 3D word cards
    [Elefant_3D.stl, Fisch_3D.stl, Hai_3D.stl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]
2023-01-21 readme pin layout table grid setup
2023-01-21 readme pin layout table grid setup 2
2023-01-21 readme pin layout table filled
2023-01-30 moved box case svg
2023-02-04 added english lowercase letter cards
    [a.stl, b.stl, c.stl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]
2023-02-05 case files with readme and dimensions
